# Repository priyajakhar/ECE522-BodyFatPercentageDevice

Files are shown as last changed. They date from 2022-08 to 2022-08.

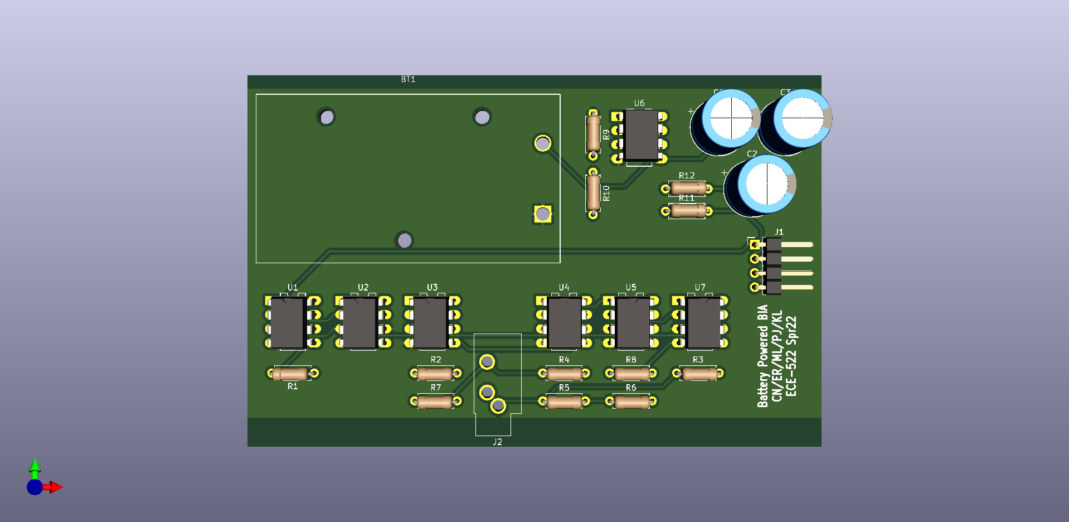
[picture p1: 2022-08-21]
Hardware/BIA_Board_Render.png

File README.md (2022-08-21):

# Body Fat Percentage Electronic Analyzer

### BIA
Body Fat percentage is a better representation of a person's nutritional state and muscle mass.

Bioelectrical impedance analysis (BIA) is a non-invasive method that uses bioelectrical impedance vector analysis (BIVA) to measure body fat percentage. BIA works by passing a fixed frequecy, low amplitude electrical current through the body via electrodes. The impedance of the body to this current results in voltage drop that hels estimate the body fat composition.

### Device
User provides basic information: gender, age and weight (in lbs) through the SerialMonitor of Arduino in the specific format of "<gender,age,weight>".
The electrical signal is produced by the device which travels through the user via the electrodes placed on the wrist and the ankle.
After about 3 seconds, the body fat percent of the user is displayed on the LCD.

### Contents:
    Device1.HEIC - Device with full enclosure
    Device2.HEIC - Device with inside components visible and working
    https://youtube.com/shorts/4t0SykkCMiM - Video of device being used by a human
    Materials List - List of all the components of the project

	Software 
		Microcontroller Software - finalCode.ino
		Microcontroller Software (earlier iteration) - draftCode.ino

	Hardware
		Schematic - "BIA_Schematic"
		PCB Layout - "BIA_Board_Layout.png"
		3D Models - "BIA_Board_Render.png"
		Enclosure 3D model - "V2Part 1.stl", "V2Part 2.stl"

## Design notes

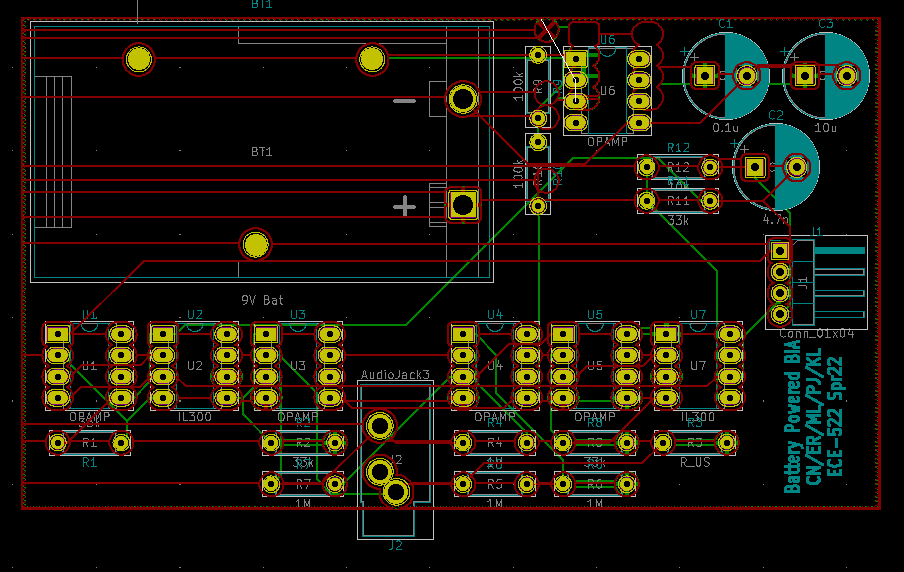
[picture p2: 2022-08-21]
Hardware/BIA_Board_Layout.PNG

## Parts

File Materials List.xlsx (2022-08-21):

BME-ECE 522 List of Materials Used
Group Name: | Team BIA
No. | Item Name | Quantity | Cost per item | Link | Total cost
1 | Arduino Nano | 1 | $14.90 | https://store-usa.arduino.cc/products/arduino-nano-every-with-headers | $14.90
2 | ECG Skin Electrodes (3/8") (50 Pack) | 1 | $17.99 | https://bio-medical.com/covidien-kendall-disposable-surface-emg-ecg-ekg-electrodes-1-3-8-35mm-50pkg.html | $17.99
3 | SHIELD-EKG-EMG-PRO Cable | 1 | $13.32 | https://www.mouser.com/ProductDetail/Olimex-Ltd/SHIELD-EKG-EMG-PRO?qs=QGk6feVlqMI7mayB%252BJy9UQ%3D%3D&mgh=1 | $13.32
5 | IL300 Linear Opto-isolater | 2 | $4.44 | https://www.mouser.com/ProductDetail/Vishay-Semiconductors/IL300?qs=xCMk%252BIHWTZOGAVSzSYFCKw%3D%3D | $8.89
6 | LF353 Op-Amp | 4 | $0.68 | https://www.digikey.com/en/products/detail/microchip-technology/MCP603-I%2FP/305934 | $2.72
7 | 20x4 LCD with I2C Module | 1 | $12.99 | https://www.amazon.com/SunFounder-Serial-Module-Arduino-Mega2560/dp/B01GPUMP9C?hvadid=309777534894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 | $12.99
8 | PRT-10811 (Barrel Jack Connector) | 1 | $0.95 | https://www.mouser.com/ProductDetail/SparkFun/PRT-10811 | $0.95
9 | Jumper Wires (Female - Male) | 1 | $4.90 | https://www.mouser.com/ProductDetail/BusBoard-Prototype-Systems/ZW-MF-20?qs=ADSrZYdIRCclfZeqZYqV2g%3D%3D | $4.90
10 | SJ1-3543N (3.5mm audio jack) | 1 | $1.42 | https://www.mouser.com/ProductDetail/CUI-Devices/SJ1-3543N?qs=WyjlAZoYn52Q7wySdDpcHg%3D%3D | $1.42
11 | 9V Battery | 1 | $3.25 | https://vetco.net/products/9v-alkaline-battery-6lr61 | $3.25
12 | PLA 3D printed housing | 200 | $0.03 |  | $6.00
 | Total Cost of Parts |  |  |  | $87.33

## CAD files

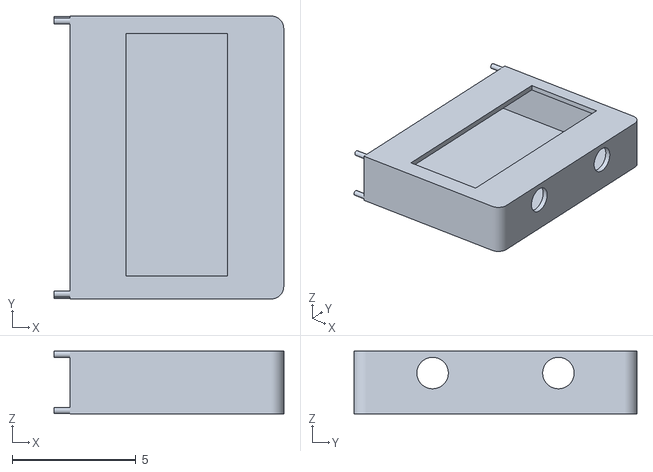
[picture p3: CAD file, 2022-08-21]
Hardware/V2Part 2.stl
9.27 x 11.4 x 2.54

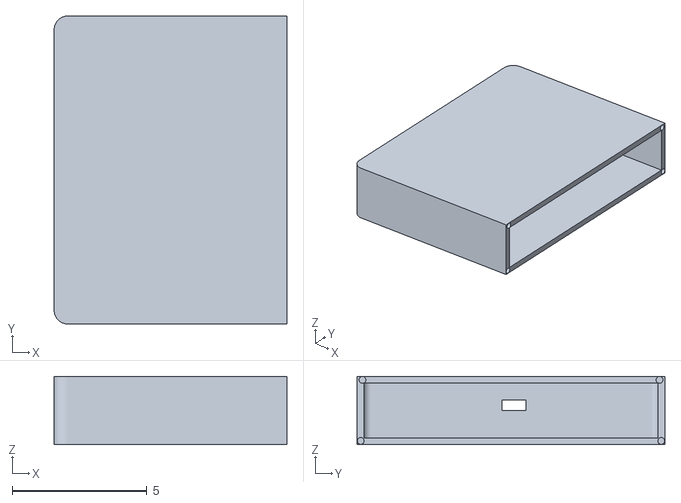
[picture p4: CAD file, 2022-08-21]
Hardware/V2Part 1.stl
8.64 x 11.4 x 2.54

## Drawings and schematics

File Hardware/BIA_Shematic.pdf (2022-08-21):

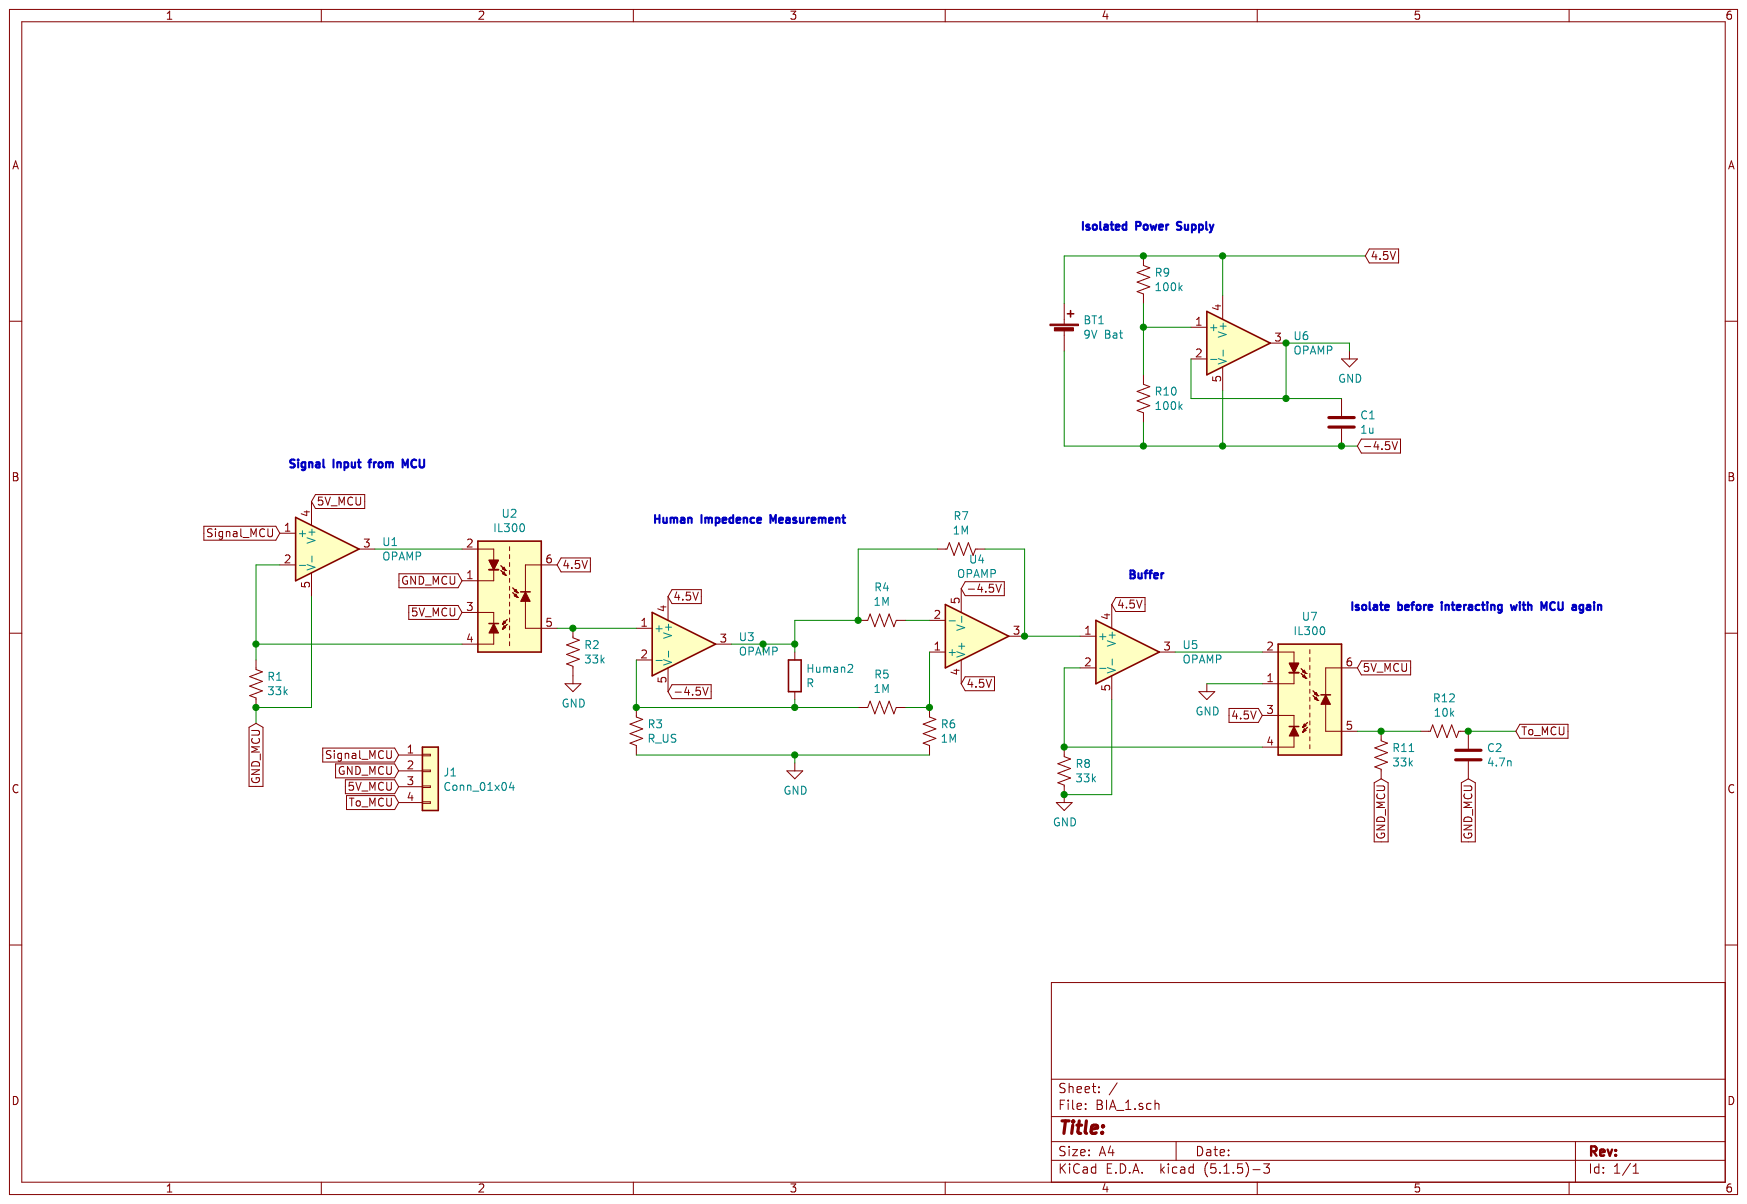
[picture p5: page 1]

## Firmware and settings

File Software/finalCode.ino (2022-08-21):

//A4 (SDA) and A5 (SCL)

#define FASTADC 1
#include <Wire.h>
#include <LiquidCrystal_I2C.h>
#define wave 3
LiquidCrystal_I2C lcd(0x27,20,4);

// define variables for setting the pre-division factor of system clock for ADC conversion
#ifndef cbi
#define cbi(sfr, bit) (_SFR_BYTE(sfr) &= ~_BV(bit))
#endif
#ifndef sbi
#define sbi(sfr, bit) (_SFR_BYTE(sfr) |= _BV(bit))
#endif

// declare the global variables
const byte numChars = 32;
char receivedChars[numChars];
char tempChars[numChars];
char gender[numChars] = {0};
int age = 0;
float weight = 0.0;
boolean newData = false;

// initialize the serial monitor, the LCD and the ADC clock speed
void setup() {
    Serial.begin(9600);
    pinMode(wave, OUTPUT);
    #if FASTADC
      sbi(ADCSRA,ADPS2) ;
      cbi(ADCSRA,ADPS1) ;
      cbi(ADCSRA,ADPS0) ;
    #endif
    lcd.init();
    lcd.backlight();
    lcd.setCursor(8,1);
    lcd.print("Hello!");
    Serial.println("Enter data <Gender (M/F), Age, Weight in lbs>"); // prompt user for input on serial monitor
}

// main function which runs only once
void loop() {
    recvWithStartEndMarkers();
    if (newData == true) {
        strcpy(tempChars, receivedChars);
        parseData();
        int volt = generateWave();
        lcdupdate(volt);
        newData = false;
    }
}

// function for getting the input from user, bound by angular brackets
void recvWithStartEndMarkers() {
    static boolean recvInProgress = false;
    static byte ndx = 0;
    char startMarker = '<';
    char endMarker = '>';
    char rc;

    while (Serial.available() > 0 && newData == false) {
        rc = Serial.read();

        if (recvInProgress == true) {
            if (rc != endMarker) {
                receivedChars[ndx] = rc;
                ndx++;
                if (ndx >= numChars) {
                    ndx = numChars - 1;
                }
            }
            else {
                receivedChars[ndx] = '\0';
                recvInProgress = false;
                ndx = 0;
                newData = true;
            }
        }
        else if (rc == startMarker) {
            recvInProgress = true;
        }
    }
}

// function for parsing the user input and assigning parts to gender, age and weight variables
void parseData() {
    char * strtokIndx;
    
    strtokIndx = strtok(tempChars,","); // get the first part
    strcpy(gender, strtokIndx); // copy it to gender
 
    strtokIndx = strtok(NULL, ","); // get the second part
    age = atoi(strtokIndx); // copy it to age
    
    strtokIndx = strtok(NULL, ","); //get the third part
    weight = atof(strtokIndx); // copy it to weight

}

// function for generating the signal to pass to the circuit which then interfaces to the user through the electrodes
// also reading and returning the analog voltage value
int generateWave() {
  long duration;
  int reading = 0.0;
  for(duration=0; duration<20000; duration++) {
    digitalWrite(wave, LOW);
    delayMicroseconds(20);
    reading = analogRead(0);
    delayMicroseconds(15);
    digitalWrite(wave, HIGH);
    delayMicroseconds(50);
  }
  return reading;
}

// function for calculating the fat percent and displaying it on the LCD
void lcdupdate(int reading){
  long body_fat = 0;
  
  if(gender[0]=='M' or gender[0]=='m')
    //body_fat = -2.2335*age+0.3624*weight-0.0078*reading; //earlier equation
	body_fat = -0.29669*age+0.3624*weight-0.0078*reading; //later equation

  else
    body_fat = -0.0698*age+0.1415*weight-0.002*reading;

  lcd.clear();
  lcd.setCursor(0,0); lcd.print("Age:");
  lcd.setCursor(9,0); lcd.print(age);
  lcd.setCursor(0,1); lcd.print("Weight:");
  lcd.setCursor(9,1); lcd.print(weight);
  lcd.setCursor(13,1); lcd.print("lbs");
  lcd.setCursor(0,3); lcd.print("Body Fat:");
  lcd.setCursor(9,3); lcd.print(body_fat);
  lcd.setCursor(11,3); lcd.print("%");
}

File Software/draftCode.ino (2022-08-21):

#define FASTADC 1
#define wave 3

// defines for setting and clearing register bits
#ifndef cbi
#define cbi(sfr, bit) (_SFR_BYTE(sfr) &= ~_BV(bit))
#endif
#ifndef sbi
#define sbi(sfr, bit) (_SFR_BYTE(sfr) |= _BV(bit))
#endif
int value = 0;
long duration = 0;
boolean exec = true;

void setup() {
  Serial.begin(9600);
  pinMode(wave, OUTPUT);
  #if FASTADC
  // set clock prescale to 16
    sbi(ADCSRA,ADPS2) ;
    cbi(ADCSRA,ADPS1) ;
    cbi(ADCSRA,ADPS0) ;
  #endif
}

void loop() {
  if(exec==true)
  {
	  // wave generation loop, duration is almost 10 secs
	  for(duration=0; duration<200000; duration++) {
		digitalWrite(wave, LOW);
		delayMicroseconds(20);
		value = analogRead(0);
		delayMicroseconds(15);
		digitalWrite(wave, HIGH);
		delayMicroseconds(50);
	  }
	  Serial.println(value);
	  exec=false;
  }
}
